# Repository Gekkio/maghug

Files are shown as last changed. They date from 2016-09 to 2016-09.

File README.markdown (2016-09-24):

# maghug

A battery-powered device that blinks a LED if it doesn't get hugs from a magnet.

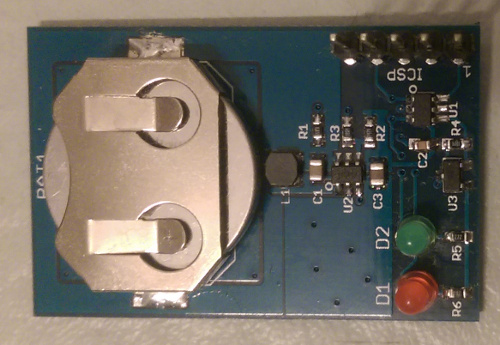
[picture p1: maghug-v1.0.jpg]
maghug v1.0


## What?

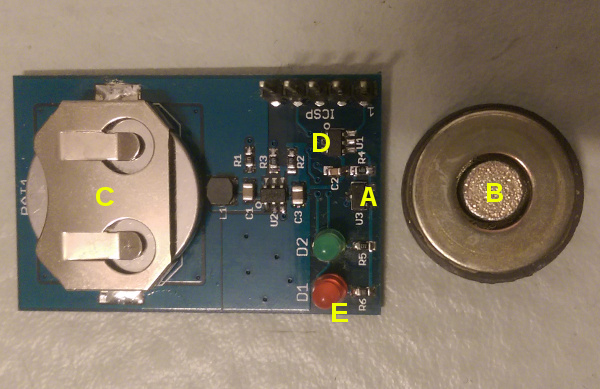
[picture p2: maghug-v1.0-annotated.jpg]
maghug v1.0 with annotations


If the magnet **(B)** near the sensor **(A)** is removed for a long period of
time, the microcontroller **(D)** powered by the CR2032 coin cell battery
**(C)** starts blinking the red LED **(E)**.

In this example the magnet is actually an old broken speaker, but any magnet of
sufficient strength will do.

## Bill Of Materials (BOM)

| Part  | Description | Mouser link |
| ----: | --- | --- |
| U1 | microcontroller, SOT-23 package | [Microchip PIC10LF322T-E/OT](http://www.mouser.com/search/ProductDetail.aspx?r=579%2dPIC10LF322T%2dE%2fOT) |
| U2 | boost regulator, SOT-23 package | [Microchip MCP16252T-I/CH](http://www.mouser.com/search/ProductDetail.aspx?r=579%2dMCP16252T%2dI%2fCH) |
| U3 | hall effect sensor, SC59 package | [Diodes Inc. AH1802-WG-7](http://www.mouser.com/search/ProductDetail.aspx?r=621%2dAH1802%2dWG%2d7) |
| L1 | 4.7 µH inductor, surface mount | [TDK VLS3015ET-4R7M](http://www.mouser.com/search/ProductDetail.aspx?r=810%2dVLS3015ET%2d4R7M) |
| R1 | 10 KΩ resistor, 0603 package | |
| R2 | 1.69 MΩ resistor, 0603 package | |
| R3 | 1 MΩ resistor, 0603 package | |
| R4 | 1 MΩ resistor, 0603 package | |
| R5 | 2.2 KΩ resistor, 0603 package | |
| R6  | 1 KΩ resistor, 0603 package | |
| C1 | 4.7 µF ceramic capacitor, 0805 package  | |
| C2 | 0.1 µF ceramic capacitor, 0603 package  | |
| C3 | 10 µF ceramic capacitor, 0805 package   | |
| D1 | Red LED, through-hole | |
| D2 | Green LED, through-hole | |
| BAT1  | CR2032 battery holder, surface mount | [Linx BAT-HLD-001](http://www.mouser.com/search/ProductDetail.aspx?r=712%2dBAT%2dHLD%2d001) |
| J1 | 0.1" header, 5 pins, through-hole | |

## License and copyright

### Hardware

Copyright 2016 Joonas Javanainen joonas.javanainen@gmail.com

The maghug hardware is licensed under a
[Creative Commons Attribution 4.0 International License](http://creativecommons.org/licenses/by/4.0/).

Eagle libraries used:

* [Gekkio Eagle Libraries](https://github.com/Gekkio/gekkio-eagle-libraries)
* [SparkFun Electronics Eagle Libraries](https://github.com/sparkfun/SparkFun-Eagle-Libraries)

### Software

Copyright 2016 Joonas Javanainen joonas.javanainen@gmail.com

Licensed under the Apache License, Version 2.0 (the "License");
you may not use this file except in compliance with the License.
You may obtain a copy of the License at

http://www.apache.org/licenses/LICENSE-2.0

Unless required by applicable law or agreed to in writing, software
distributed under the License is distributed on an "AS IS" BASIS,
WITHOUT WARRANTIES OR CONDITIONS OF ANY KIND, either express or implied.
See the License for the specific language governing permissions and
limitations under the License.

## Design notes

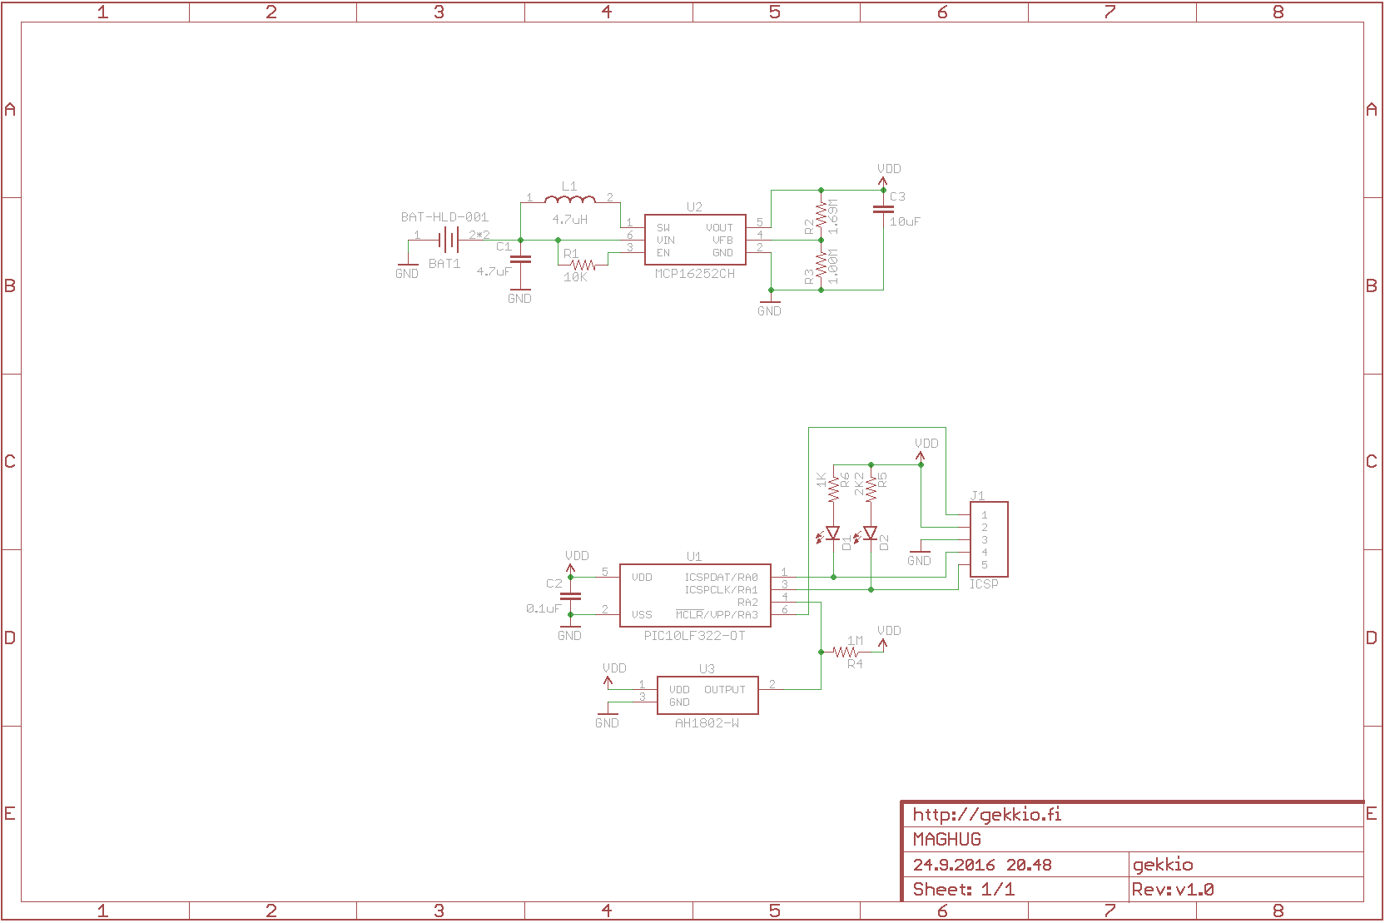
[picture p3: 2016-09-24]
MAGHUG-v1.0.sch.png

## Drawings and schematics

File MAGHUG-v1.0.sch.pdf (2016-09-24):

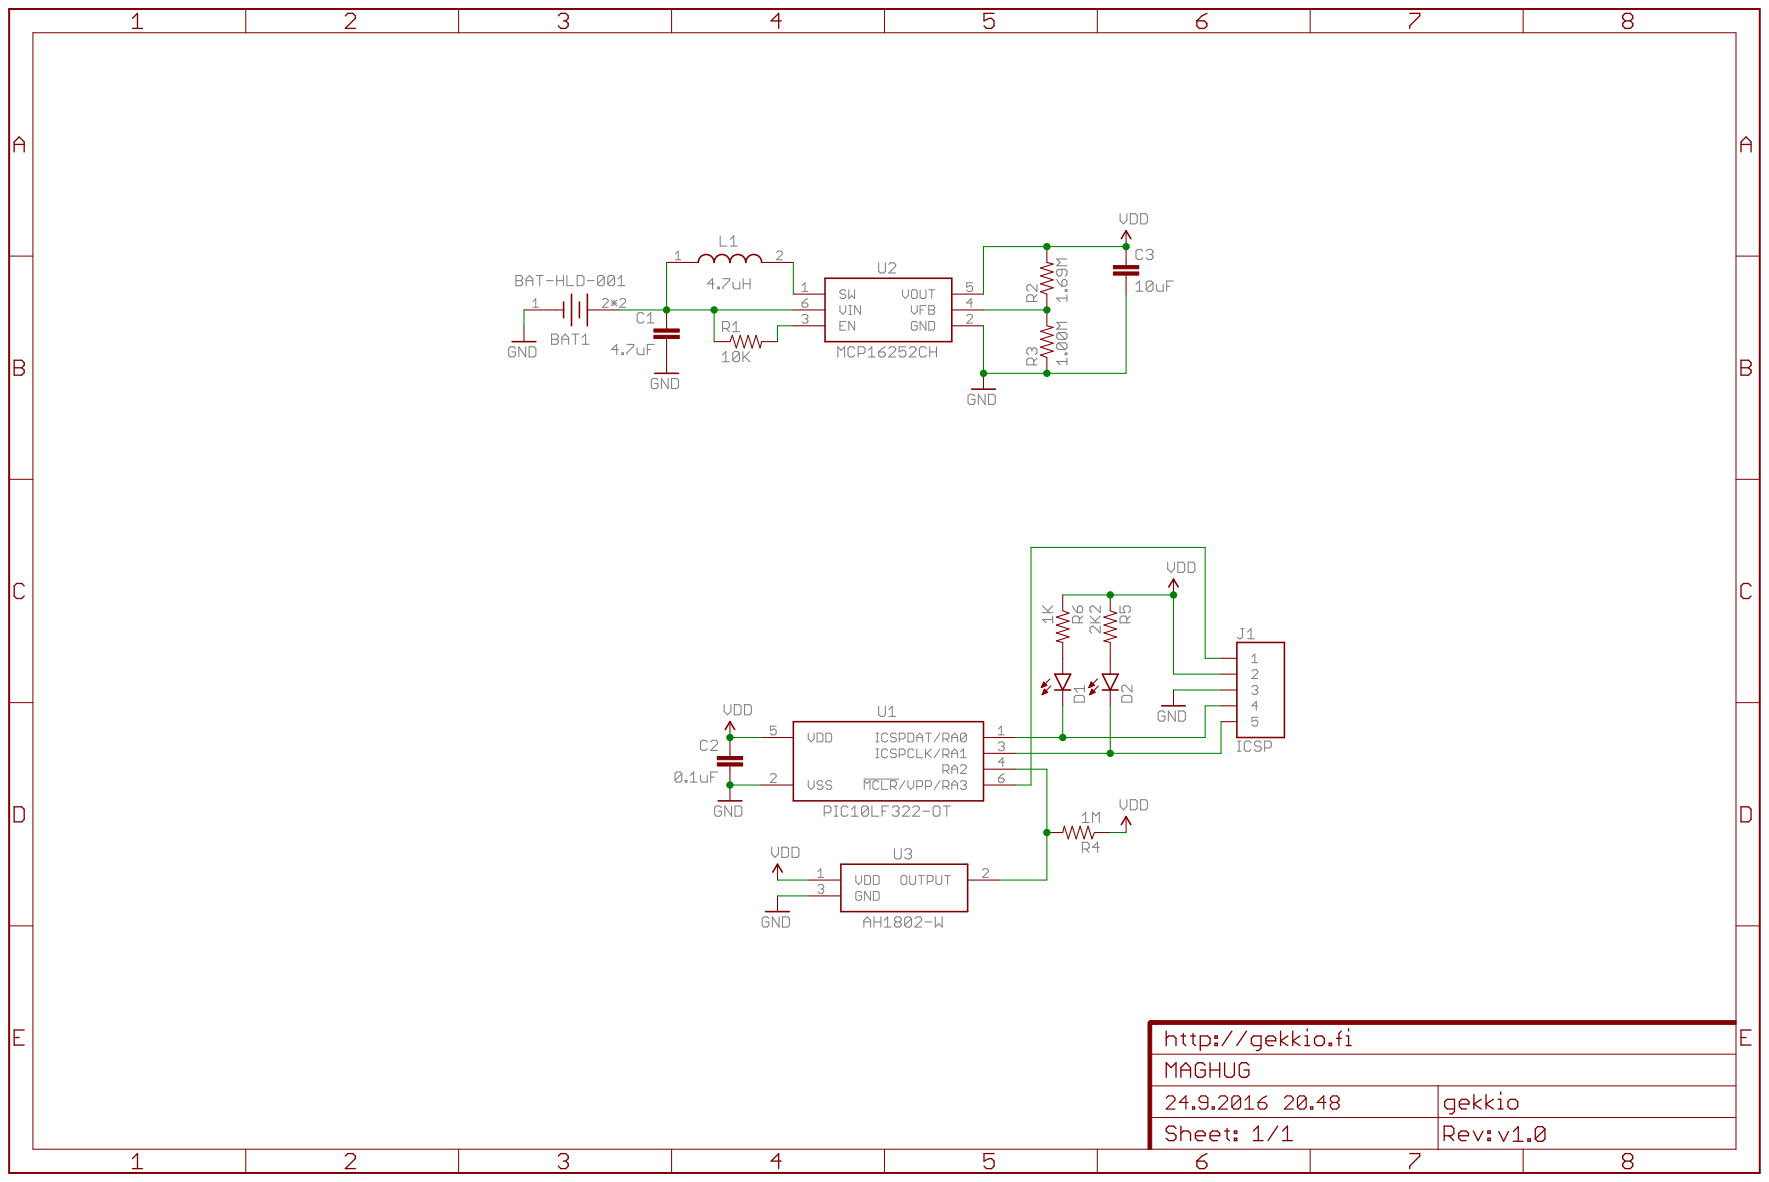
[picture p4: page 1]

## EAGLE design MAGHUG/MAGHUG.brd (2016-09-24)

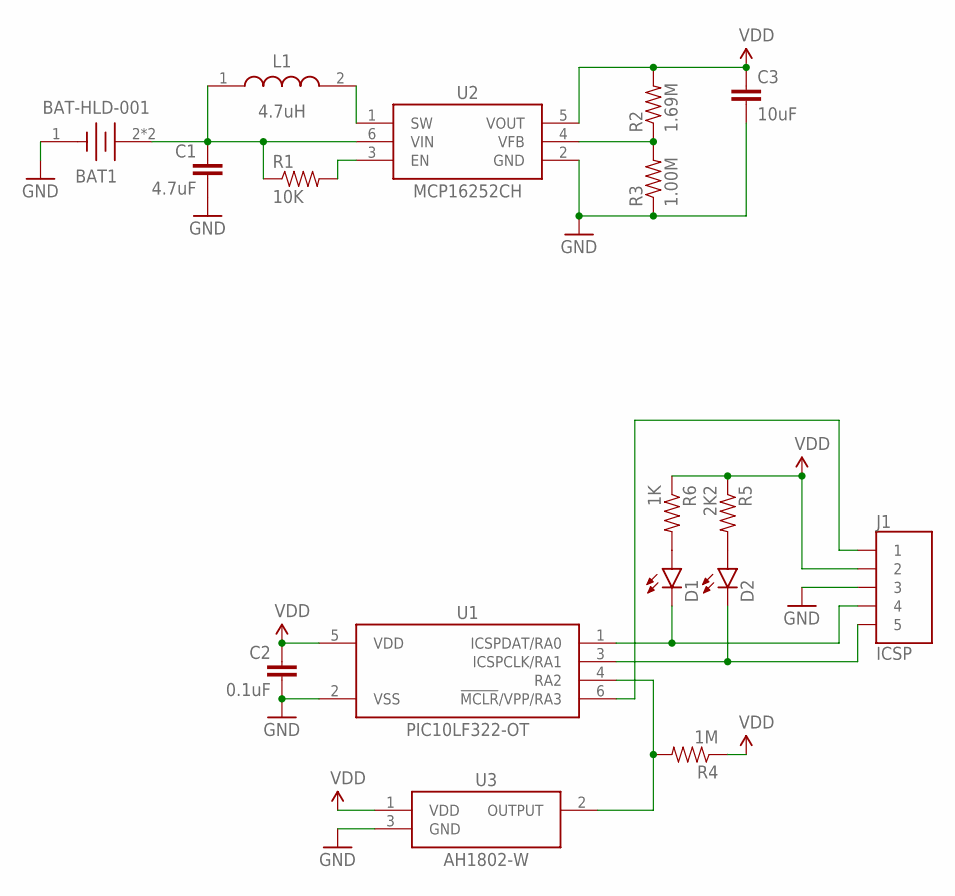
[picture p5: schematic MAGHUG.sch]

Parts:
BAT1: BAT-HLD-001
C1: 4.7uF; 0805
C2: 0.1uF; 0603-CAP
C3: 10uF; 0805
D1, D2: LED-3MM-NO_SILK; LED3MM-NS
J1: ICSP; 1X5-LONGPADS
L1: 4.7uH; VLS3015E
R1: 10K; 0603-RES
R2: 1.69M; 0603-RES
R3: 1.00M; 0603-RES
R4: 1M; 0603-RES
R5: 2K2; 0603-RES
R6: 1K; 0603-RES
U1: PIC10LF322-OT; SOT-23(CH/CHY/OT)
U2: MCP16252CH; SOT-23(CH/CHY/OT)
U3: AH1802-W; SC59

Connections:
!MCLR: J1.1, U1.6 (!MCLR!/VPP/RA3)
EN: R1.2, U2.3 (EN)
GND: BAT1.1 (-), C1.2, C2.2, C3.2, J1.3, R3.1, U1.2 (VSS), U2.2 (GND), U3.3 (GND)
unnamed: R4.2, U1.4 (RA2), U3.2 (OUTPUT)
unnamed: D1.A, R6.2
unnamed: D2.A, R5.2
RA0: D1.K (C), J1.4, U1.1 (ICSPDAT/RA0)
RA1: D2.K (C), J1.5, U1.3 (ICSPCLK/RA1)
SW: L1.2, U2.1 (SW)
VBAT: BAT1.2 (+), BAT1.3 (+), C1.1, L1.1, R1.1, U2.6 (VIN)
VDD: C2.1, C3.1, J1.2, R2.2, R4.1, R5.1, R6.1, U1.5 (VDD), U2.5 (VOUT), U3.1 (VDD)
VFB: R2.1, R3.2, U2.4 (VFB)

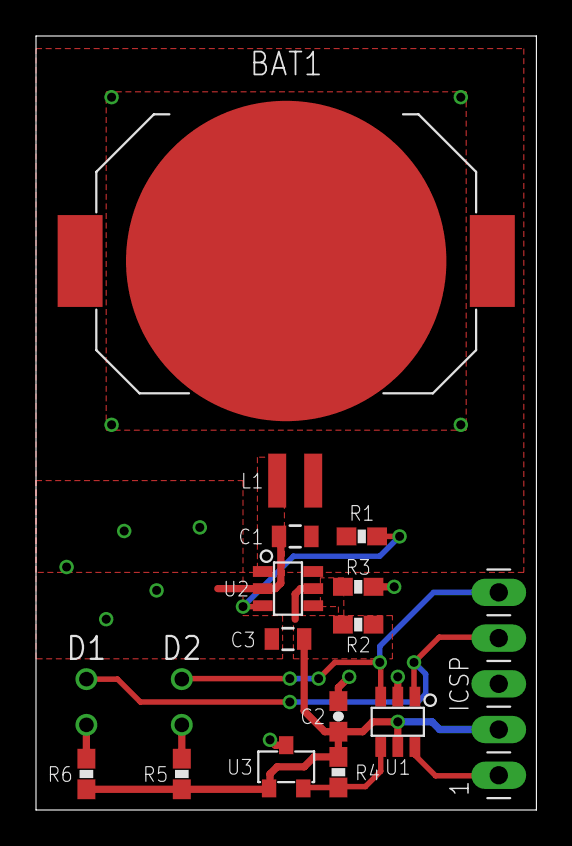
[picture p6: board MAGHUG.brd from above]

Board: 2 copper layers, 27.8 x 43.0 mm, 17 parts (0 on the bottom side), 12 nets.

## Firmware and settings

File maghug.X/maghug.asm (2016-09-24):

; Copyright 2016 Joonas Javanainen joonas.javanainen@gmail.com
;
; Licensed under the Apache License, Version 2.0 (the "License");
; you may not use this file except in compliance with the License.
; You may obtain a copy of the License at
;
;     http://www.apache.org/licenses/LICENSE-2.0
;
; Unless required by applicable law or agreed to in writing, software
; distributed under the License is distributed on an "AS IS" BASIS,
; WITHOUT WARRANTIES OR CONDITIONS OF ANY KIND, either express or implied.
; See the License for the specific language governing permissions and
; limitations under the License.

#include "p10lf322.inc"

; CONFIG
;   __config 0x3FDE
    __CONFIG _FOSC_INTOSC & _BOREN_ON & _WDTE_ON & _PWRTE_ON & _MCLRE_ON & _CP_OFF & _LVP_ON & _LPBOR_ON & _BORV_LO & _WRT_OFF

    CONSTANT MAX_ALARM_COUNT = 1

    UDATA
alarm_count RES 1

res_vect CODE 0x0000
    GOTO start

main_program CODE
start:
    CLRF PORTA
    CLRF LATA
    CLRF ANSELA
    MOVLW B'00000100'
    MOVWF PORTA
    MOVLW B'11111100'
    MOVWF TRISA

    MOVLW B'00000000'
    MOVWF OSCCON
wait_osc:
    BTFSS OSCCON, 1
    GOTO wait_osc

begin_sleep_mode:
    BSF PORTA, 0
    BSF PORTA, 1

    MOVLW (MAX_ALARM_COUNT + 1)
    MOVWF alarm_count

loop_sleep:
    MOVLW B'00011010'
    MOVWF WDTCON
    SLEEP

    BTFSS PORTA, 2
    GOTO loop_sleep_blink

    DECFSZ alarm_count
    GOTO loop_sleep_blink
    GOTO begin_alarm_mode

loop_sleep_blink:
    MOVLW B'00001110'
    MOVWF WDTCON

    BCF PORTA, 1
    SLEEP
    BSF PORTA, 1
    GOTO loop_sleep

begin_alarm_mode:
    MOVLW B'00010100'
    MOVWF WDTCON
loop_alarm:
    SLEEP

    BTFSS PORTA, 2
    GOTO begin_sleep_mode

    MOVLW B'00000001'
    XORWF PORTA, 1
    GOTO loop_alarm

    END

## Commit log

2016-09-24 Add a photo of v1.0 board
2016-09-24 Add a short explanation of what the device does

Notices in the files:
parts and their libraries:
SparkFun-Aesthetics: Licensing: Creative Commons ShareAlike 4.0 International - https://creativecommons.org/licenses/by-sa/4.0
